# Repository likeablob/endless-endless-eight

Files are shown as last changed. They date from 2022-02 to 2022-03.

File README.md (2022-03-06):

<p align="center">
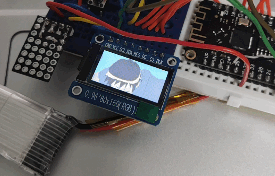
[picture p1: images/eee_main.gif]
  
  <p align="center">
  <small>The clip played is from The Melancholy of Haruhi Suzumiya (2009). </small>
  </p>
</p>

# Endless Endless Eight

A self-sustained AVI player to replay the summer days.

- ESP32 to play MJPEG-AVI video files from microSD at 24 fps.
- Utilizes ULP coprocessor for BAT voltage monitoring, Deep Sleep management etc.
- 5V solar panel and small LiPo battery as the main power source.
- (Planned) LTC3130-1 for more efficient power conversion.

## BOM

**WIP**

- ESP32 WeMos LOLIN32 Lite
- ST7735 80x160 LCD module
- microSD card (>= 2 GB)
- 5V 2W solar panel

## Prepare video files

All the video files to be placed on the MicroSD must be MJPEG-encoded AVI.

```sh
# Transcode EP 12~19 to ee_%d.avi, with scaling and cropping
$ seq 12 19 | xargs -L 1 -P1 -I% bash -c 'ffmpeg -i ee_%.mp4 -r 24 -vf scale=160:-1,crop=160:80 -vcodec mjpeg -q:v 5 -an ee_%.avi -y'
```

See [sdcard/](./sdcard/) for a set of sample vid files. These are converted from [BigBuckBunny.mp4](http://commondatastorage.googleapis.com/gtv-videos-bucket/sample/BigBuckBunny.mp4).

```sh
# The sample vid files were from
$ seq 12 19 | xargs -L 1 -P1 -I% bash -c 'ffmpeg -ss $(((% - 12)*2)) -to $(((% - 12 + 1) * 2)) -i BigBuckBunny.mp4 -r 24 -vf scale=160:-1,crop=160:80 -vcodec mjpeg -q:v 5 -an ee_%.avi -y'
```

## Build firmware

```sh
$ git clone https://github.com/likeablob/endless-endless-eight.git
$ cd endless-endless-eight

$ cp include/user_config.g.template cp include/user_config.h
$ code include/user_config.h

$ pio run || pio run # The very 1st run may fail due to ulptool-pio
$ pio run -t upload
```

## Print enclosure

See [./enclosure](./enclosure).

## How it works

### State transitions

Centering on the deep sleep mode, this application has several wake-up states as depicted in the following diagram.

- The application switches back-and-forth between the nominal mode and deep sleep depending on the battery voltage. (See [Power management strategy](#power-management-strategy) for details.)
- Also, under the certain condition, it wakes in;
  - Emergency mode to prepare for a complete power loss (See [State persistence](#state-persistence))
  - Periodic Reporting mode for reporting housekeeping data via MQTT
- Basically every wake up transition is triggered by the ULP routine.

```mermaid
stateDiagram-v2
    Playing: Playing Video (Nominal)
    [*] --> Playing
    Playing --> DeepSleep: At low battery
    DeepSleep --> Playing: At high battery

    DeepSleep --> Emergency: At very low battery
    Emergency --> DeepSleep: ASAP

    DeepSleep --> PeriodicReporting: Every 30 minutes
    PeriodicReporting --> DeepSleep: ASAP
```

### Power management strategy

It's quite simple; Wake the Main CPU up if `the battery voltage (BAT_V) >= 3.9 V` and put into sleep if `BAT_V <= 3.75 V`.  
The ULP co-processor executes own routine every one second, but still is able to keep the deep sleep current consumption at uA-level.

```mermaid
flowchart TB
  subgraph CPU["Main CPU"]
    %% flow
    power_boot(" ")
    boot("Boot")
    check_ulp_boot{"Wake by ULP?"}
    init_ulp["Init ULP routine"]

    %% flow
    init_loop(" ")
    check_batv_sleep{"BAT_V <= SLEEP_TH"}
    sleep("Deep sleep")

    power_boot --> boot --> check_ulp_boot
    check_ulp_boot -->|"Yes"| init_loop
    check_ulp_boot -->|"No"| init_ulp --> init_loop

    init_loop --> check_batv_sleep
    check_batv_sleep -->|"Yes"| sleep
    check_batv_sleep -->|"No"| init_loop
    sleep -.-> |"Wake by ULP"| boot
  end

  subgraph ULP
    %% nodes
    boot_ulp(" ")
    measure_batv["Measure Battery voltage (BAT_V) by ADC"]
    check_batv_wake{"BAT_V >= WAKE_TH"}
    wake_main["Wake Main CPU"]
    end_ulp(" ")

    %% flow
    boot_ulp --> measure_batv --> check_batv_wake
    check_batv_wake -->|"Yes"| wake_main ---> end_ulp
    check_batv_wake --->|"No"| end_ulp

    end_ulp -.->|"Every 1 sec"| boot_ulp
  end

  %% flow
  init_ulp -.-> boot_ulp
```

### State persistence

The play state such as a file playing, its position and loop count etc. are kept over deep sleep or even complete power outage, thanks to ~~Nagato~~ [RTC SLOW MEM](https://docs.espressif.com/projects/esp-idf/en/latest/esp32/api-reference/system/sleep_modes.html#overview) and [Non-Volatile Storage](https://docs.espressif.com/projects/esp-idf/en/latest/esp32/api-reference/storage/nvs_flash.html). The former is volatile but survives deep sleep, and the latter is nothing but a reserved region in flash.

In short there are two pathways for each storage.

- A. Save to `RTC_SLOW_MEM` before entering deep sleep. Restore from `RTC_SLOW_MEM` after waking up from deep sleep.
- B. Save to `NVS` at very-low battery voltage. Restore from `NVS` on boot.

Note: About B., the ULP routine wakes the main CPU in the Emergency mode when `BAT_V <= 3.55 V`. This happens only once and the related flag will be cleared by the main CPU after normal wake up.

```mermaid
flowchart
  %% nodes
  init(" ")
  check_ulp_boot{"Wake by ULP?"}
  restore_from_nvs["Restore from Non-volatile storage"]
  restore_from_rtc["Restore from RTC SLOW RAM\n(Volatile, Deep-sleep persistent)"]
  check_ulp_flag_emergency{"Emergency Mode?\n(caused by very low battery)"}
  save_to_nvs["Save to Non-volatile storage"]
  sleep("Deep sleep")
  init_loop("Main Loop")
  check_low_bat{"Low battery?"}
  save_to_rtc["Save to RTC SLOW MEM"]

  init ---> check_ulp_boot
  check_ulp_boot -->|"Yes"| check_ulp_flag_emergency
  check_ulp_boot -->|"No"| restore_from_nvs --> init_loop
  check_ulp_flag_emergency --> |"Yes"| save_to_nvs --> sleep
  check_ulp_flag_emergency --> |"No"| restore_from_rtc --> init_loop

  init_loop --> check_low_bat
  check_low_bat --> |"Yes"| save_to_rtc --> sleep
  check_low_bat --> |"No"| init_loop

  sleep -.-> init

  classDef restore fill:#dce4ef,stroke:#333,stroke-width:2px;
  classDef save fill:#e7f4e4,stroke:#333,stroke-width:2px;
  class restore_from_nvs,restore_from_rtc restore
  class save_to_nvs,save_to_rtc save
```

## LICENSE

MIT

## Dependencies

This projects is here thanks to a lot of superb OSS libraries.
See [platformio.ini](./platformio.ini) for details. Thank you to all the devs.

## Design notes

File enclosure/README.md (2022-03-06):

# EEE Enclosure

## Models

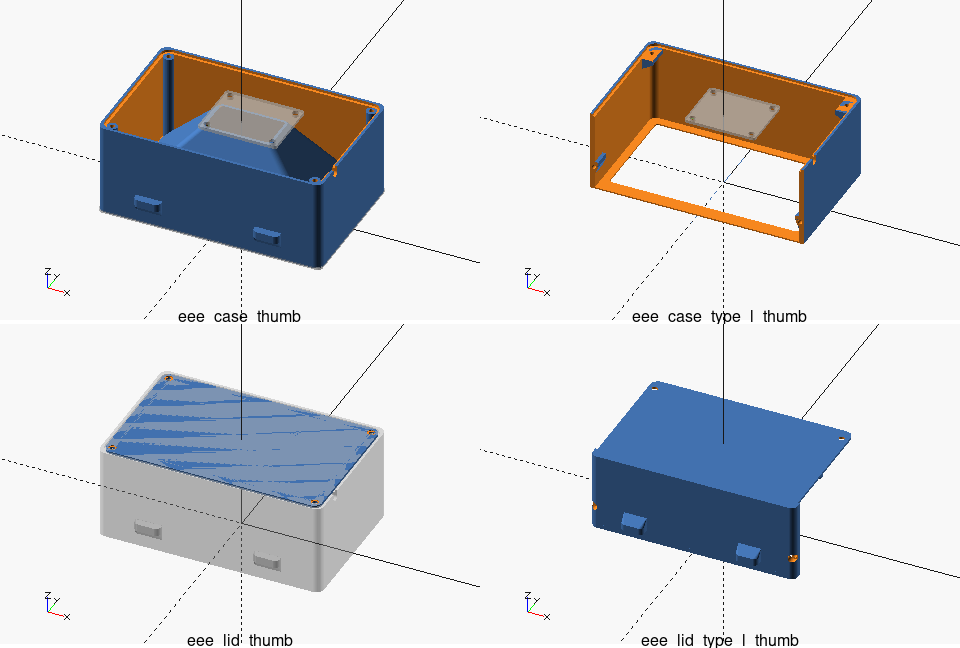
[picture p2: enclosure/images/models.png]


## Recommended printing configuration

- PLA
- Layer: 0.2 mm

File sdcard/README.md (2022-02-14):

```
Big Buck Bunny Copyright (C) 2008 Blender Foundation | peach.blender.org Some Rights Reserved.
Creative Commons Attribution 3.0 license. https://peach.blender.org/
```

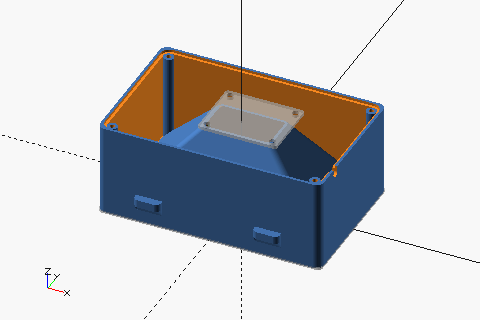
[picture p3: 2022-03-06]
enclosure/images/eee_case_thumb.png

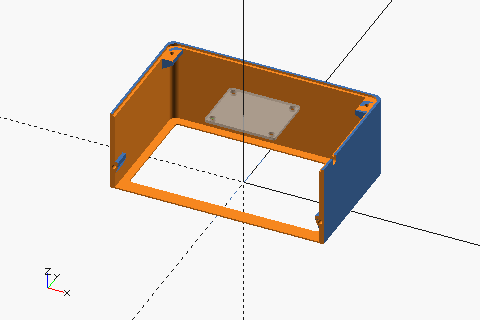
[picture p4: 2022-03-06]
enclosure/images/eee_case_type_l_thumb.png

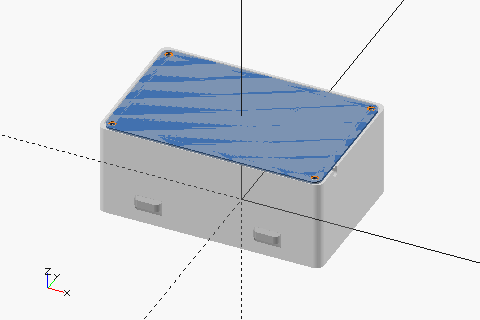
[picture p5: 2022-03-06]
enclosure/images/eee_lid_thumb.png

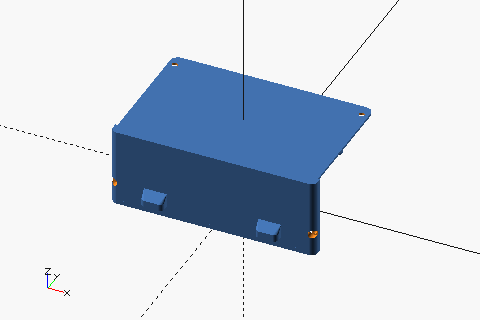
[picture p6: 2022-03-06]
enclosure/images/eee_lid_type_l_thumb.png

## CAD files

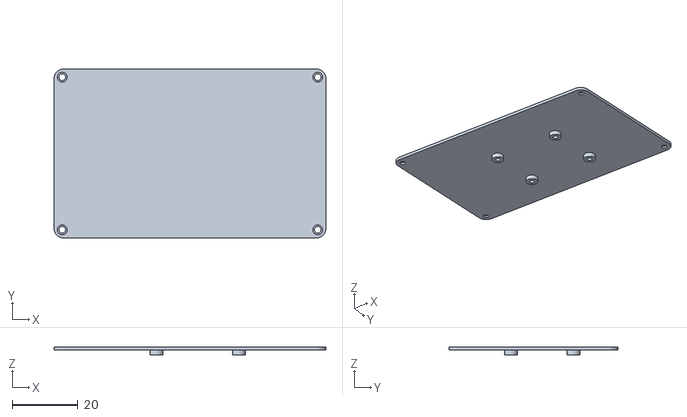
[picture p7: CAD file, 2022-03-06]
enclosure/eee_lid.stl
82.5 x 51.3 x 2.50

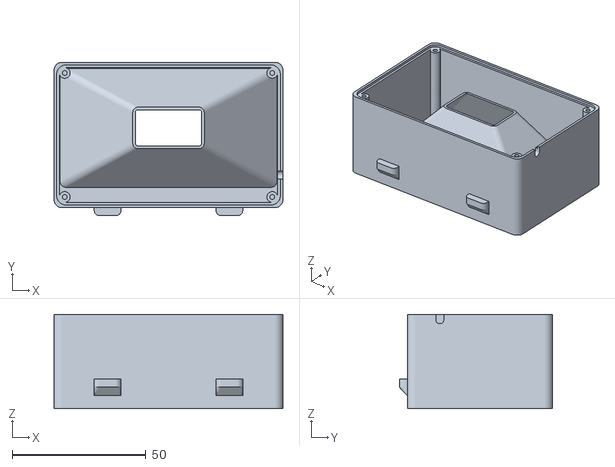
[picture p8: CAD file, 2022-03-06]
enclosure/eee_case.stl
85.5 x 57.3 x 35.2

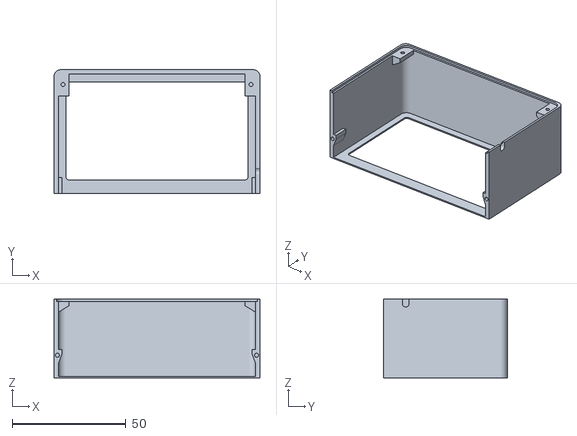
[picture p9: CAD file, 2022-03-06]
enclosure/eee_case_type_l.stl
90.5 x 54.3 x 34.7

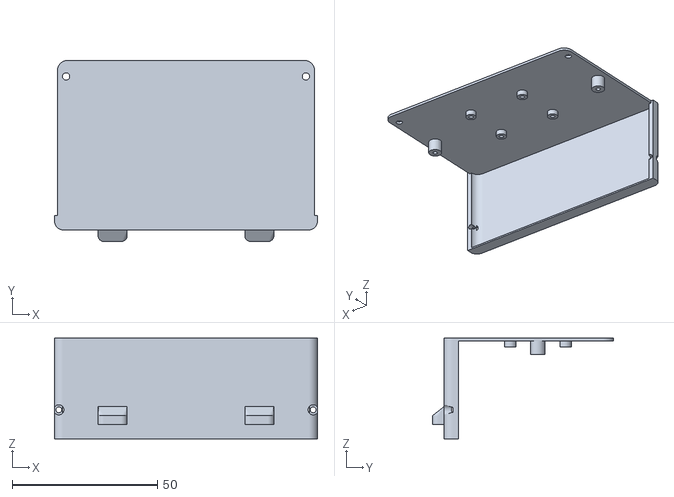
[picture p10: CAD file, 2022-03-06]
enclosure/eee_lid_type_l.stl
90.5 x 62.3 x 34.7

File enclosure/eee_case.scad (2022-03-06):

include <modules/eee_case.scad>

%
lens_body();

eee_body();

%
translate_to_lens_effective_center()
translate_to_lcd_z_plane()
translate_to_lcd_center(as_center=true)
lcd_module_body();

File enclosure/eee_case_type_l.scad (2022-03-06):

include <modules/eee_case_type_l.scad>

*
translate([0, 0, EEE_BODY_FRONT_Z]) 
lens_body();

eee_body();

%
translate_to_lens_effective_center()
translate_to_lcd_z_plane()
translate_to_lcd_center(as_center=true)
lcd_module_body();

*
%
eee_lid_body();

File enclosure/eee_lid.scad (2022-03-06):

include <modules/eee_case.scad>

*
%
lens_body();

%
eee_body();

%
translate_to_lens_effective_center()
translate_to_lcd_z_plane()
translate_to_lcd_center(as_center=true)
lcd_module_body();


translate([0, 0, EEE_BODY.z - EEE_LID.z]) 
eee_lid_body();

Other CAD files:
enclosure/eee_lid_type_l.scad
enclosure/modules/eee_case.scad
enclosure/modules/eee_case_type_l.scad
enclosure/modules/flesnel_lens.scad
enclosure/modules/lcd_096in_st7735.scad

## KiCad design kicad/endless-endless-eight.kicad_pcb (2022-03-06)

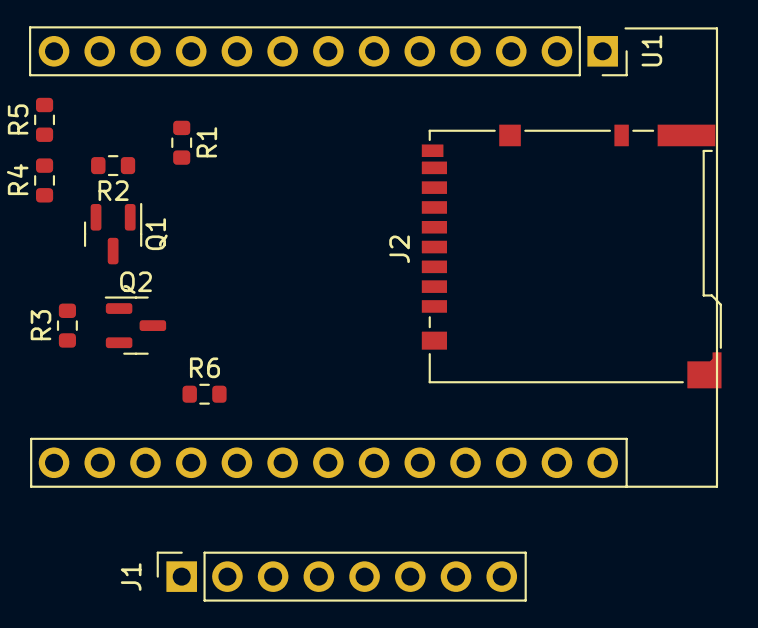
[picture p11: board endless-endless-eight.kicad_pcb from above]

Board: 2 copper layers, 11 parts (0 on the bottom side), 18 nets, no tracks yet.

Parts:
J1: 0.96in_80x160_st7735s_LCD_module; PinSocket_1x08_P2.54mm_Vertical
J2: Micro_SD_Card_Det; microSD_HC_Hirose_DM3BT-DSF-PEJS
Q1: Q_NMOS_GSD; SOT-23
Q2: Q_PMOS_GSD; SOT-23
R1: 100; R_0603_1608Metric
R2, R3, R4, R5: 10k; R_0603_1608Metric
R6: 2k; R_0603_1608Metric
U1: esp32_wemos_lolin32_lite

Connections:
+3V3: Q2.2 (S), R3.1, U1.26 (3v3)
BAT_V_MON: R4.2, R5.1, U1.4 (34)
BUS_POWER: J1.2, J2.4 (VDD), Q2.3 (D), R6.1
BUS_POWER_SW: R1.1, U1.9 (26)
LCD_CS: J1.7, U1.21 (5)
LCD_DC: J1.6, U1.20 (17)
LCD_GND: J1.1, J2.6 (VSS), Q1.2 (S), R2.2, R5.2, U1.13 (GND)
LCD_RES: J1.5, U1.19 (16)
LCD_SCL: J1.3, U1.22 (18)
LCD_SDA: J1.4, U1.23
unnamed: Q1.1 (G), R1.2, R2.1
unnamed: Q1.3 (D), Q2.1 (G), R3.2
SDIO_CLK: J2.5 (CLK), U1.11 (14)
SDIO_CMD: J2.3 (CMD), U1.15
SDIO_DAT0: J2.7 (DAT0), R6.2, U1.16 (2)
SDIO_DAT1: J2.8 (DAT1), U1.18 (4)
SDIO_DAT2: J2.1 (DAT2), U1.12
SDIO_DAT3: J2.2 (DAT3/CD), U1.14 (13)

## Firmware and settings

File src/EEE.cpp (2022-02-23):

#include "EEE.h"

const char *vidFiles[] = {"/ee_12.avi", "/ee_13.avi", "/ee_14.avi",
                          "/ee_15.avi", "/ee_16.avi", "/ee_17.avi",
                          "/ee_18.avi", "/ee_19.avi"};
const uint16_t vidFilesLen = sizeof(vidFiles) / sizeof(vidFiles[0]);

EEE_ &EEE_::getInstance() {
    static EEE_ instance;
    return instance;
}

EEE_ &EEE = EEE.getInstance();

const char *EEE_::_getVidFile(uint16_t ind) {
    return vidFiles[ind % vidFilesLen];
}

bool EEE_::_tftOutputCallback(int16_t x, int16_t y, uint16_t w, uint16_t h,
                              uint16_t *bitmap) {
    // Stop further decoding as image is running off bottom of screen
    if(y >= EEE.tft.height())
        return 0;

    EEE.tft.pushImage(x, y, w, h, bitmap);

    // Decode next block
    return 1;
}

void EEE_::_requestFirstVidFile() {
    fileInd = 0;
    frameInd = 0;
    shouldLoadFile = FileLoadReason::NEXT_FILE_REQUESTED;
}

bool EEE_::begin() {
    // Init SDMMC
    if(!SD_MMC.begin()) {
        Serial.println("Card Mount Failed");
        return false;
    }

    uint8_t cardType = SD_MMC.cardType();
    if(cardType == CARD_NONE) {
        Serial.println("No SD_MMC card attached");
        return false;
    }

    // Init TFT
    tft.init();             // initialize a ST7735 (80x160), see platformio.ini
    tft.setSwapBytes(true); // Swap the colour bytes (endianess)
    tft.setRotation(3);
    tft.fillScreen(TFT_BLACK);

    // Init JPG decoder
    TJpgDec.setJpgScale(1);
    TJpgDec.setCallback(this->_tftOutputCallback);

    // Init periodic tasks
    renderTask.start();

    return true;
}

bool EEE_::handle() {
    // Load the next vid file if requested.
    if(shouldLoadFile != FileLoadReason::CLEARED) {
        // Preserve preloaded frameInd on LOAD_AFTER_BOOT
        frameInd =
            (shouldLoadFile == FileLoadReason::LOAD_AFTER_BOOT) ? frameInd : 0;

        const char *path = _getVidFile(fileInd);
        Serial.printf("Loading a file: %s\n", path);

        uint32_t tInit = millis();
        avi_parser_err_t err = aviParser.init(SD_MMC, path);
        if(err) {
            Serial.printf("An error returned by aviParser.init(): 0x%x\r\n",
                          err);
            fileInd = 0;
            frameInd = 0;
            // Keep shouldLoadFile to reload the file in the next loop.
            return false;
        }
        Serial.printf("tInit: %lu ms\r\n", millis() - tInit);
        shouldLoadFile = FileLoadReason::CLEARED;
    }

    if(renderTask.hasPassed(EE_MSEC_PER_FRAME)) {
        renderTask.restart();
        return renderFrame();
    }

    return true;
}

bool EEE_::renderFrame() {
    uint32_t tLoad = millis();

    // Load index data
    AviIndexData indexData;
    avi_parser_err_t err;

    err = aviParser.readIndex(frameInd, indexData);
    if(err == AVI_PARSER_LAST_FRAME) {
        Serial.printf("Reached to the end. fileInd: %u\n", fileInd);
        fileInd = (fileInd + 1) % vidFilesLen;
        shouldLoadFile =
            FileLoadReason::NEXT_FILE_REQUESTED; // Load the next file in the
                                                 // next loop
        loopCount++;
    } else if(err != AVI_PARSER_OK) {
        Serial.printf("An error returned by readIndex(): 0x%x\r\n", err);
        _requestFirstVidFile();
        return false;
    }

    // Load frame data
    uint8_t *imgData = (uint8_t *)malloc(indexData.dwChunkLength);
    err = aviParser.readFrame(indexData, imgData);
    if(err) {
        Serial.printf("An error returned by readFrame(): 0x%x\r\n", err);
        free(imgData);
        _requestFirstVidFile();
        return false;
    }
    tLoad = millis() - tLoad;

    // Draw the frame
    uint32_t tRender = millis();
    TJpgDec.drawJpg(0, 0, imgData, indexData.dwChunkLength);
    free(imgData);
    tRender = millis() - tRender;

    // Check if it's speedy enough
    if(renderTask.elapsed() > EE_MSEC_PER_FRAME) {
        Serial.printf("Running late! elapsed: %lu ms, frameInd: %u \r\n",
                      renderTask.elapsed(), frameInd);
        Serial.printf("tLoad: %u ms, tRender: %u ms\r\n", tLoad, tRender);
    }

    frameInd++;

    return true;
}

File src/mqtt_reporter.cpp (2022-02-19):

#include "mqtt_reporter.h"

AsyncMqttClient mqttClient;
volatile SemaphoreHandle_t xMutex = NULL;

void onConnected(bool persisted) {
    Serial.printf("onConnected: %d\n", persisted);

    if(xMutex) {
        xSemaphoreGive(xMutex);
    }
}
void onPublish(uint32_t packetId) {
    Serial.printf("onPublish: %x\n", packetId);
    if(xMutex) {
        xSemaphoreGive(xMutex);
    }
}

void onDisconnect(AsyncMqttClientDisconnectReason reason) {
    Serial.printf("onDisconnect: %x\n", reason);
    if(xMutex) {
        xSemaphoreGive(xMutex);
    }
}

void MqttReporter::begin() {
    mqttClient.onConnect(onConnected);
    mqttClient.onPublish(onPublish);
    mqttClient.onDisconnect(onDisconnect);
    mqttClient.setServer(MQTT_HOST, MQTT_PORT);

    xMutex = xSemaphoreCreateMutex();
    xSemaphoreTake(xMutex, 0);

    pinMode(BUILTIN_LED, OUTPUT);
    digitalWrite(BUILTIN_LED, HIGH); // OFF
}

void MqttReporter::report(mqtt_data_map_t &dataMap) {
    size_t tReport = millis();
    digitalWrite(BUILTIN_LED, LOW);

    // Get the lower 3 bytes of 6 byte MAC
    // aa:bb:cc:dd:ee:ff -> dd:ee:ff
    // (3 byte shift, byte-swap and 1 byte shift)
    uint32_t partialMac = __bswap_32(ESP.getEfuseMac() >> 24) >> 8;
    String clientId = String("eee-") + String(partialMac, HEX);

    // Init WiFi
    WiFi.setHostname(clientId.c_str());
    if(!WiFi.isConnected()) {
        WiFi.mode(WIFI_STA);
        WiFi.begin(WIFI_SSID, WIFI_PASSWORD);
    }
    if(WiFi.waitForConnectResult() != WL_CONNECTED) {
        Serial.println("WiFi connection failed.");
        return;
    }

    // Init MQTT client
    size_t tConnect = millis();
    mqttClient.setClientId(clientId.c_str());
    mqttClient.connect();
    if(xSemaphoreTake(xMutex, 3000) == pdTRUE) {
        Serial.println("mqttClient connected");
    } else {
        Serial.println("mqttClient connect() timeout");
    }
    Serial.printf("tConnect: %u\n", millis() - tConnect);

    // Publish data
    uint8_t qos = 0;
    for(auto iter = dataMap.begin(); iter != dataMap.end(); iter++) {
        if(std::next(iter) == dataMap.end()) {
            qos = 1; // FIXME: dirty hack to trigger onPublish() cb
        }
        mqttClient.publish(
            String(MQTT_TOPIC_PREFIX + clientId + "/" + iter->first).c_str(),
            qos, false, iter->second.c_str());
    }
    if(xSemaphoreTake(xMutex, 6000) == pdTRUE) {
        Serial.println("Successfully published");
    } else {
        Serial.println("publish() not ACKed");
    }

    // Disconnect from the MQTT server
    size_t tDisconnect = millis();
    mqttClient.disconnect(false);
    if(xSemaphoreTake(xMutex, 6000) == pdTRUE) {
        Serial.println("mqttClient disconnected");
    } else {
        Serial.println("mqttClient disconnect() timeout");
    }
    Serial.printf("tDisconnect: %u\n", millis() - tDisconnect);

    // Disconnect from the AP and stop WiFi stack
    // by wifioff=true', esp_wifi_stop() will be called internally
    WiFi.disconnect(true);

    digitalWrite(BUILTIN_LED, HIGH);
    Serial.printf("tReport: %lu\n", millis() - tReport);
}

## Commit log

2022-02-14 Add sample vids
2022-02-19 Better ADC ref voltage based on measurements
2022-02-19 Workaround for stable wake-up after WiFi.disconnect(true)
    [mqtt_reporter.cpp]
2022-02-19 Implement emergency mode for saving variables into non-volatile memory
    - Add `loopCount` to EEE for tracking number of files played.
    - Implement emergency mode in main app:
    - Save variables (frameInd, etc.) to non-volatile memory when it's woken in
    the Emergency mode where BAT voltage is below the threshold.
    - Use Preferences Library (which is backed by ESP32 nvs) as storage backend.
    - Minor fix to let the main code to clear WAKE_VOLTAGE_SATISFIED flag just before
    entering into Deep sleep.
    [EEE.cpp, pm.cpp]
2022-02-23 Start deep sleep on error instead of reset
    [EEE.cpp]
2022-03-06 Apply LPF to ULP ADC reading
2022-03-06 Add schematics made with EESchema
    [endless-endless-eight.kicad_pcb, endless-endless-eight.kicad_sch]
2022-03-06 Add .scad and .stls of casing
    [eee_case.scad, eee_case.stl, eee_case_type_l.scad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]
2022-03-06 Add enclosure/README
